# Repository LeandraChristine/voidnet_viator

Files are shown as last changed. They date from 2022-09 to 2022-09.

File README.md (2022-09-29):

# voidnet_viator
Scripts, code and printable 3d-files for the Voidnet Viator Cyberdeck

## Description
A savage, retro-cyberpunk inspired Cyberdeck with a focus on human interface, finished for the Hackaday Cyberdeck challenge 2022.

Built to be a heavy-haptics, typing-friendly and portable device with a comparatively low profile the Viator also features a few add-ons for hardware hacking.
The custom made high ergonomic roll-pin mouse pointer allows typing on the mechanical keyboard and mouse movement in the same hand position.
This interface is supported by a wide-screen touchscreen, a psp-knob used for scrolling, stereo speakers, USB Hub, a tiny status OLED, GPIO switches + LEDs, and a
CharliePlex visualization of the currently used memory.
To enable project building, 5V power is supplied via two banana jacks and a 8 channel signal analyzer mounted under the keyboard.
A grip handle, cable-containing shoulder strap, flashlight and two 18650 Lion cells make the Viator a viable companion for your next run.

## Links
Video: https://clipchamp.com/watch/iuDfoU8I1nf

3d Model overview - Fusion: https://a360.co/3SyB80R

3d Files and Scripts - Github: https://github.com/LeandraChristine/voidnet_viator

Build - Hackerspace WIKI: https://www.hackerspace-ffm.de/wiki/index.php?title=Voidnet_Viator_Cyberdeck

## BOM

Other than the 3d printed parts (all FDM parts printed in black PETG, all Resin printed in Elegoo ABS-like clear-red) the following was used:

### Base
- Raspberry Pi 4 (+SD card)
- Corsair K65 RGB 60% mechanical keyboard (don't get too attached to it)
- Waveshare Raspberry Pi 7.9 inch Capacitive LCD HDMI Display 400 x 1280 (comes with great Raspi HDMI and USB connectors)
- Geekworm Raspberry Pi UPS, X728 V2.1 (or alternative)
- 2x 18650 (unprotected due to the X728 spacing) Lion cells
- 2x Goobay 4-Port USB 2.0 Hub (needs a super slim form factor to fit. I used this: https://www.berrybase.de/4-port-usb-2.0-hub-mit-0-4m-anschlusskabel-farbe-schwarz)
- Stero USB Speaker (2 x 0,5W, I used: https://www.berrybase.de/externer-usb-mini-lautsprecher-schwarz)
- Alumnium Angle 40mm x 20mm, cut to a length of 290mm (the 3d files include 2 drill-guides to help get the holes right)
- 3x 4mm Brass rods ~330mm length (cut a 1m part into 3, to clamp the 3d printed parts cut a thread at the end of each rod)
- M4 Nuts to secure the clamping shell to the brass rods
- M2 cylinder screws of various lengths
- M2.5 screws and standoffs of various lengths (for the raspi, USP and waveshare display)
- M3 cylinder screws of various lengths
- Wiring (e.g. 0.14mm), Connectors and general soldering stuff
- Some USB and MINI-USB connectors to solder (to configure custom wires that are slim enough below the keyboard)
- Threaded inserts / Knurled Nuts (M3) (pretty much used everywhere)
- (optional) microSD / T-Flash to microSD extension (to get to the SD card easier)

### Rolling mouse
- 8mm stainless steel shaft
- 3x IGUS drylin® R Lineargleitbuchse RJUM-01 (or LM8UU, but it will not feel as nice and smooth)
- optics, chip and bits off a cheap, wired, optical mouse (I used ISY ICM-1000, which has a A2803 optical mouse sensor: http://www.nst-ic.com/nstfileupload/productsinfo/20190703095231_293.pdf)

### Additional Features
- Adafruit 15x7 CharliePlex LED Matrix Display FeatherWing - Red
- Adafruit OLED for Raspberry Pi Pico, 128x32, I2C (scratch that, it died randomly and was replaced by a Generic 0.91 Inch, White 128X32 I2C OLED)
- AZDelivery Logic Analyzer 8 CH, 24MHz
- 2x 4mm Banana Jacks (22mm length, one red, one black...I did not like the red I got so a 3d file for resin printing your own is included)
- InLine 33441G USB 3.1 Adaptercable Male C to Female C (for the charging port connected to the UPS)
- 0.28" mini Digital Voltmeter Display
- (optional) 4x WAGO 221-412 2 Fach clamps (to expose the I2C Bus on the backside)
- PSP Slim analog Controller Joystick
- Teensy LC (to generate a HID Keyboard and Mouse, you can try a different controller here....but I had some issues with the Circuitpython ones)
- 7x different color 5mm LEDS (and resistors matched to the GPIO output)
- 7x LED housing for 5mm leds (I used Signal Construct 1089)
- 4x Miniature Toggle Switch (I scavenged for these, you can also use any other switches or buttons that fit in the front panel)
- Hefty, vandalism-safe Button with LED indicator for 10mm hole (power button, there is plenty of space reserved for this in the housing so even longer models should fit)
- 5mm hole momentary switch (for below the screen, wired to the waveshare display's on/off switch so it can be used to conserve power)

### Handle
- Bike Handle Grip (Diameter: ~24 mm. Length: ~ 110 mm, cut to size)
- Aluminum Pipe 24mm OD, 20mm ID
- M5 threaded rod ~140mm length
- 2x M5 Ring nut (screws to the threaded rod)

### Strap
- 2x Tactical Belt (so you get two buckles to remove the strap completely)
- Some more M3 Bolts & Nuts
- USB or other cables you wish to carry
- Cable ties (to attach the belt-buckles to the 4mm rods on the main case)

### Greeblies
- 2x CPU cooler above the speaker covers
- 1x rectangular cooler on the left side

### Experimental
- SMALLRIG Ultra Slim 4K HDMI Kabel  Micro HDMI Male to Full HDMI Female 14cm (to expose the 2nd HDMI output on the back, but so far I did not get that to work nicely)

## Build
For info on the building process check the Hack-FFM Wiki: https://www.hackerspace-ffm.de/wiki/index.php?title=Voidnet_Viator_Cyberdeck

### 3d-Files
If you wish to build a similar device you can probably use a lot of the printed parts, while modifying others to suit your needs.
The parts are available on github: https://github.com/LeandraChristine/voidnet_viator

### Scripts

.ino Files in the teensy folder are for the Teensy LC HID device. Flash them to the teensy with your method of choice (e.g. arduino). Make sure to flash as USB Keyboard + Mouse + Joystick

.py Files can be called via crontab (sudo crontab -e, and then add a line like @reboot python3 /pathtothefile to start the script at boot)
stats.py displays some general status of the system on the tiny OLED
shellcharlie.py visualizes the memory status on the CharliePlex display
the GPIO scripts can be modified to trigger LEDs and take input from switches (the example uses side LEDs to show the battery charge)

## THX
HackFFM - https://hackaday.io/hackerspace/167562-hackerspace-ffm (especially for helping with the photo shoot and replacements for suddenly dying hardware)
For the nice background: https://geekprank.com/hacker/simulator/

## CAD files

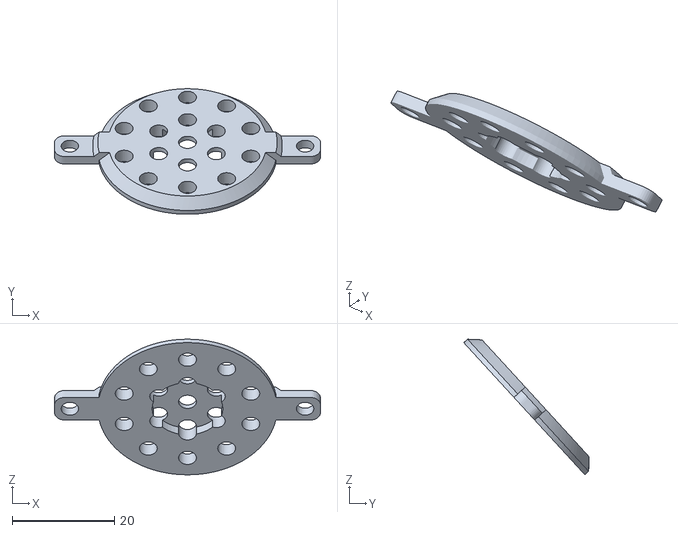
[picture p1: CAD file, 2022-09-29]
3d_files/FDM/Speaker_Cover.stl
51.9 x 24.5 x 26.5

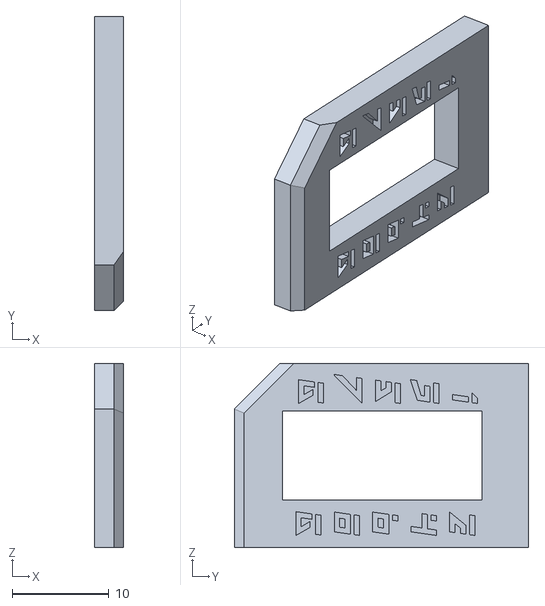
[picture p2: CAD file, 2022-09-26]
3d_files/RESIN/AnalyzerLabel_RESIN.stl
3.00 x 30.4 x 19.0

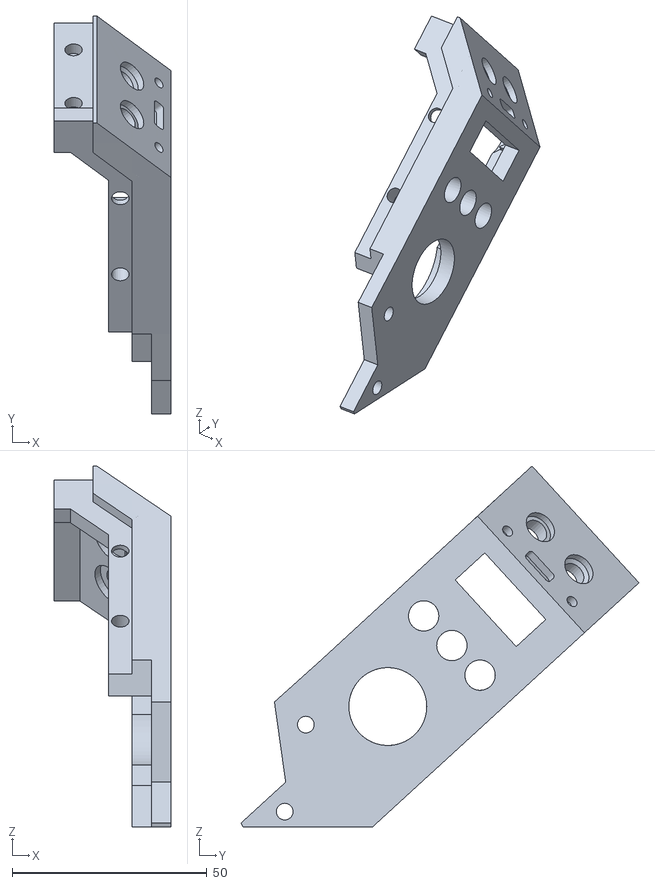
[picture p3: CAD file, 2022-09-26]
3d_files/FDM/Right_Front_Holder.stl
30.0 x 102.2 x 92.6

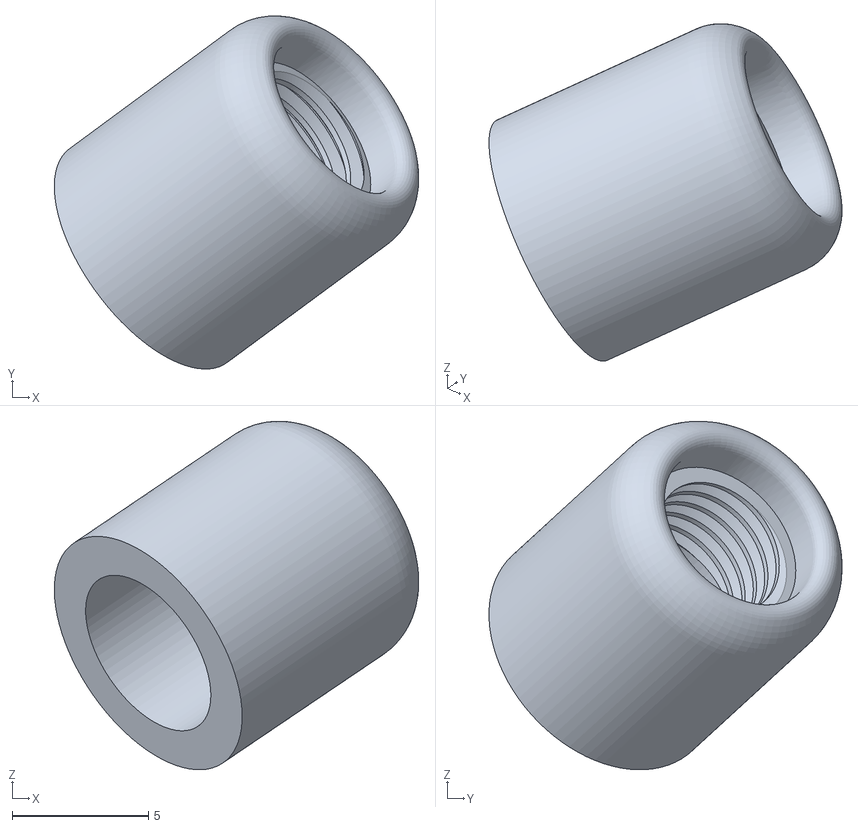
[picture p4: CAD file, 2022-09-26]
3d_files/RESIN/V_Buchse_RESIN.stl
13.4 x 13.0 x 12.8

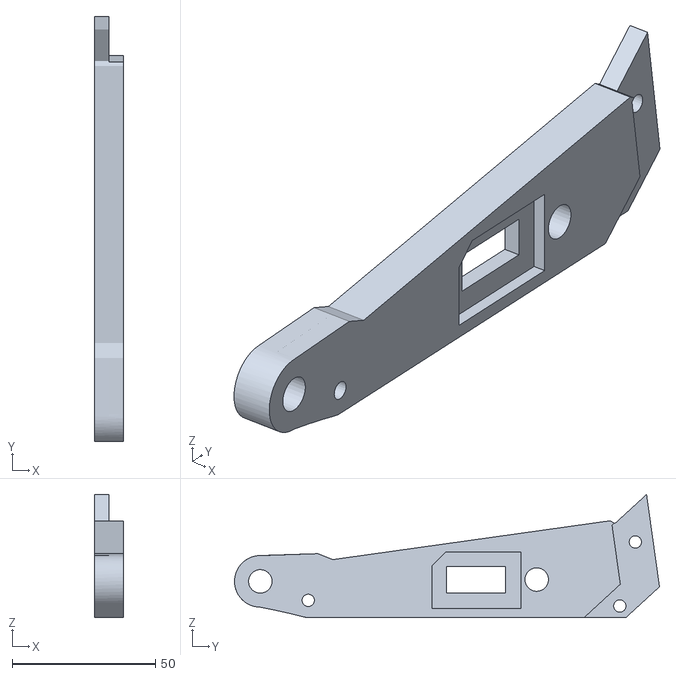
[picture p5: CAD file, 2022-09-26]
3d_files/FDM/Right_Bracket.stl
10.0 x 148.2 x 42.9

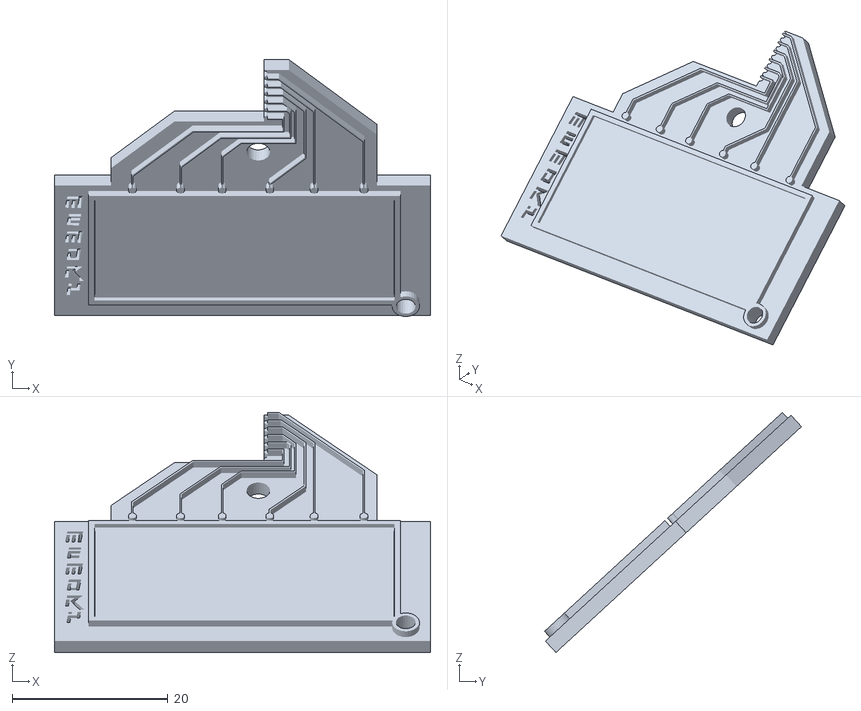
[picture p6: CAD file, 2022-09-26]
3d_files/RESIN/Screen_RESIN.stl
48.4 x 33.1 x 30.9

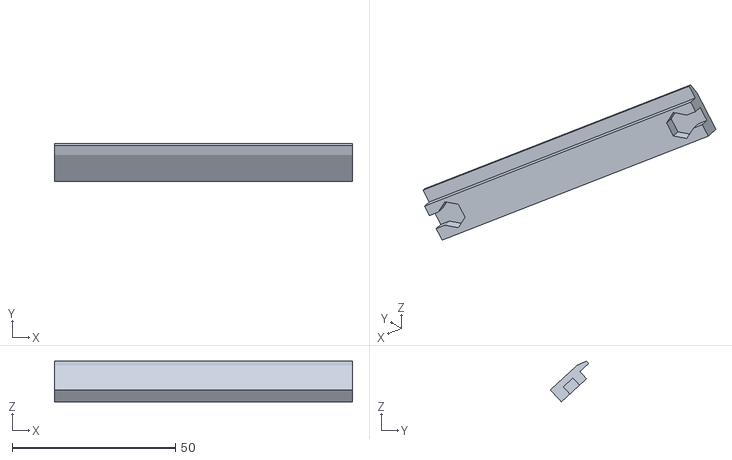
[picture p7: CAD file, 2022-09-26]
3d_files/FDM/Extension_Bot.stl
91.2 x 11.8 x 12.5

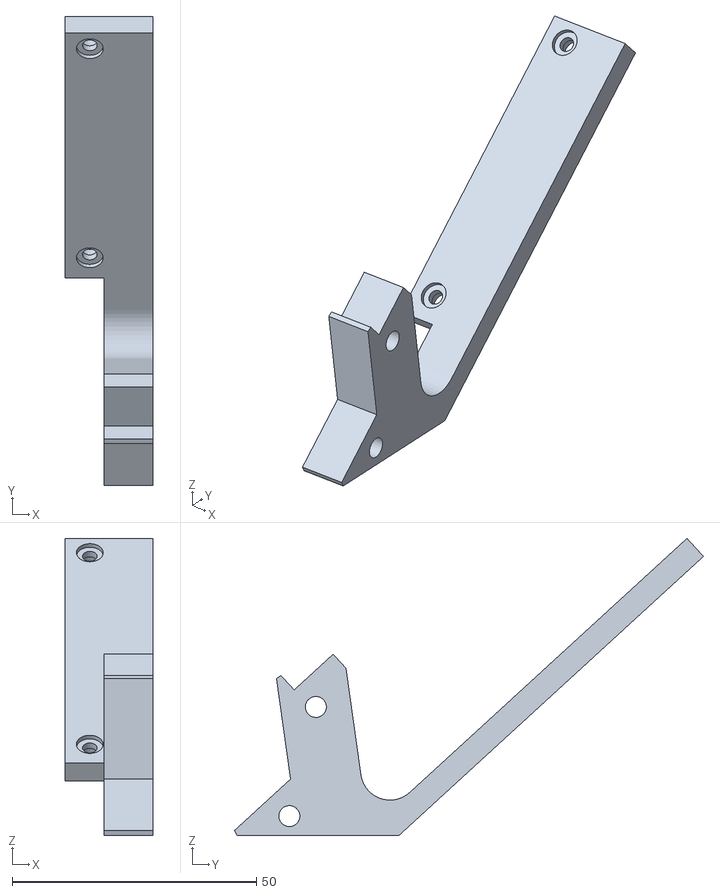
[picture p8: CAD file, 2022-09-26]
3d_files/FDM/Back_Attachment_Broad.stl
18.0 x 96.0 x 60.8

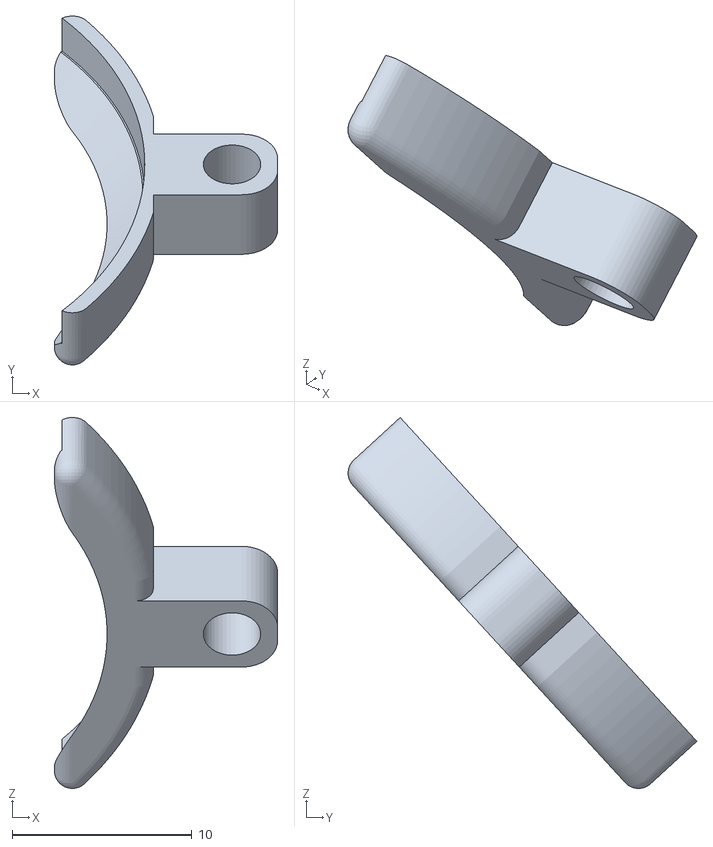
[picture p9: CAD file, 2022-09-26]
3d_files/FDM/Speaker_Holder.stl
12.4 x 19.4 x 20.7

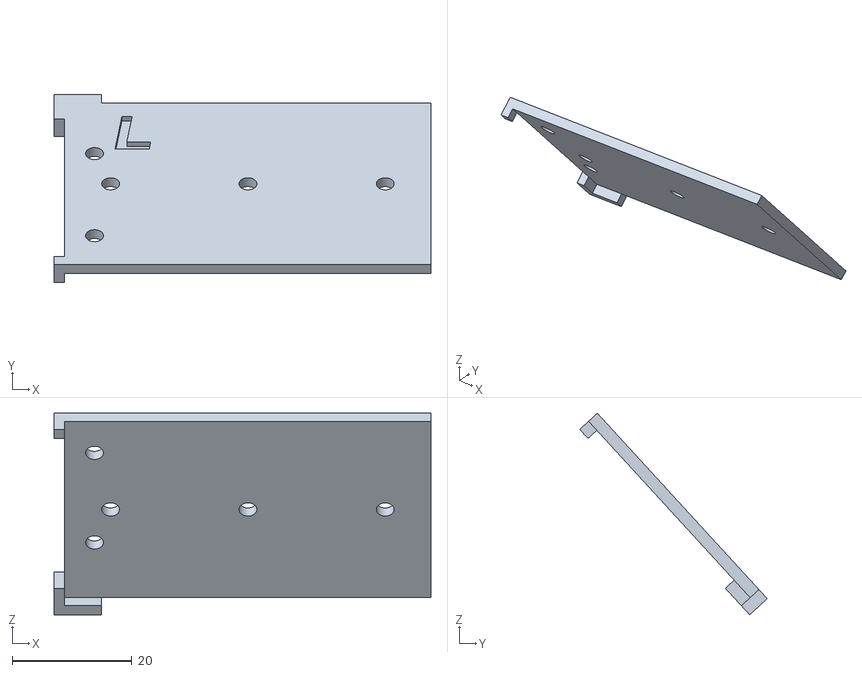
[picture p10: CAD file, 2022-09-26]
3d_files/FDM/Drillguide_Left.stl
63.0 x 31.4 x 33.7

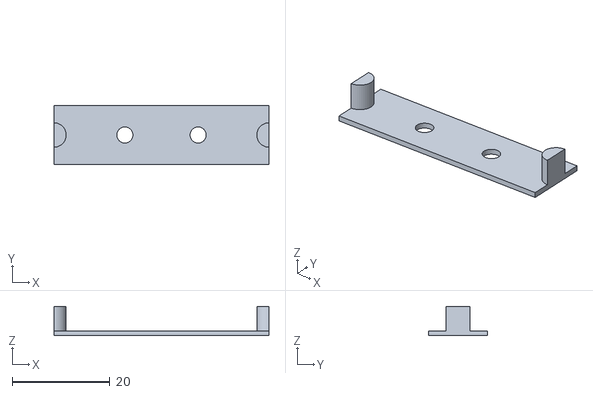
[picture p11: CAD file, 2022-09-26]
3d_files/FDM/Cable_Clamp_Bot.stl
44.0 x 12.0 x 6.00

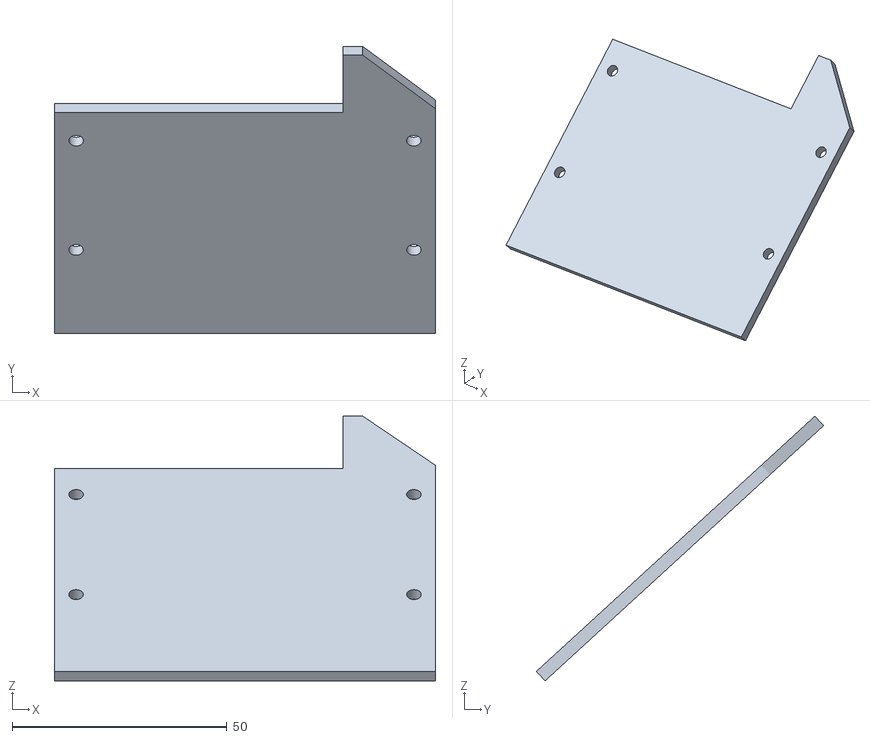
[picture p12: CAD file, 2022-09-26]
3d_files/FDM/Backplate_2.stl
88.7 x 66.9 x 61.6

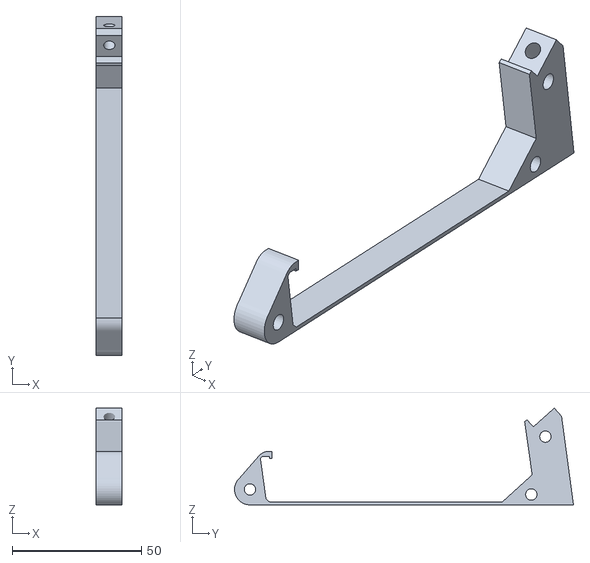
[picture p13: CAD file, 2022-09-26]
3d_files/FDM/Stable_Bracket.stl
10.0 x 130.9 x 37.4

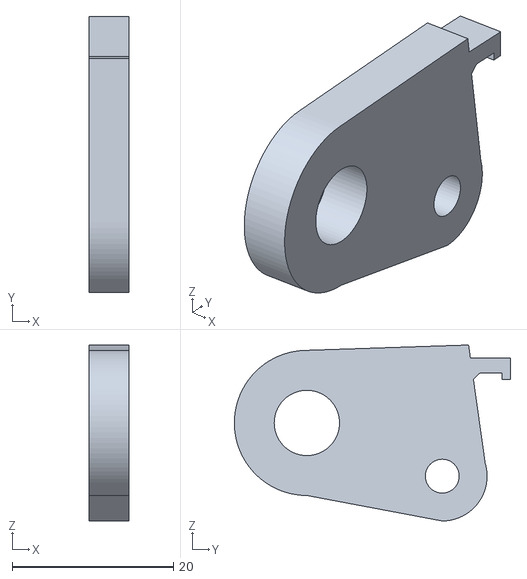
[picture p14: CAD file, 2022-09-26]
3d_files/FDM/Axel_Clamp.stl
5.00 x 34.3 x 21.8

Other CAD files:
3d_files/FDM/Left_Bracket.stl
3d_files/FDM/Optical_Mouse_Cover.stl
3d_files/FDM/Optical_Mouse_Casing.stl
3d_files/FDM/Backplate_1.stl
3d_files/FDM/Back_Attachment_Left.stl
3d_files/FDM/Backplate_3.stl
3d_files/FDM/Cable_Clamp_Top.stl
3d_files/FDM/Display_Panel.stl
3d_files/FDM/Drillguide_Right.stl
3d_files/FDM/Extension_Top.stl
3d_files/FDM/FrontPanel_Clip.stl
3d_files/FDM/Grip_Holder_Back.stl
3d_files/FDM/Grip_Holder_Front.stl
3d_files/FDM/Left_Front_Holder.stl
3d_files/FDM/Left_Panel.stl
3d_files/FDM/Right_Panel.stl

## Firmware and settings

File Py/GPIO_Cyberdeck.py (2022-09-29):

import RPi.GPIO as GPIO
import time
import struct
import smbus
import sys

# Global settings
# GPIO is 26 for x728 v2.0 v2.1 v2.2, GPIO is 13 for X728 v1.2/v1.3
#GPIO_PORT 	= 26 right now used by a LED in the wiring...might have to change that...
I2C_ADDR    = 0x36 #address of the power mgt chip in the X728

LED_FRONT_0 = 6
LED_FRONT_1 = 13
LED_FRONT_2 = 19
LED_FRONT_3 = 26

LED_SIDE_BACK = 23
LED_SIDE_MID = 24
LED_SIDE_FRONT = 25

SW_1 = 21
SW_2 = 20
SW_3 = 16
SW_4 = 12

LEDS_FRONT = [LED_FRONT_0, LED_FRONT_1, LED_FRONT_2, LED_FRONT_3]
LEDS_SIDE = [LED_SIDE_FRONT, LED_SIDE_MID, LED_SIDE_BACK]
LEDS = LEDS_FRONT + LEDS_SIDE
SWITCHES = [SW_1, SW_2, SW_3, SW_4]


#Function from the SW example on the X728 project page
def readVoltage(bus):

     address = I2C_ADDR
     read = bus.read_word_data(address, 2)
     swapped = struct.unpack("<H", struct.pack(">H", read))[0]
     voltage = swapped * 1.25 /1000/16
     return voltage

#Function from the SW example on the X728 project page
def readCapacity(bus):

     address = I2C_ADDR
     read = bus.read_word_data(address, 4)
     swapped = struct.unpack("<H", struct.pack(">H", read))[0]
     capacity = swapped/256
     return capacity

bus = smbus.SMBus(1) # 0 = /dev/i2c-0 (port I2C0), 1 = /dev/i2c-1 (port I2C1)

GPIO.setmode(GPIO.BCM)

for LED in LEDS:
    GPIO.setup(LED, GPIO.OUT)
    #print("LED out set " + str(LED))
    
for SW in SWITCHES:
    GPIO.setup(SW, GPIO.IN, pull_up_down=GPIO.PUD_UP)
    #print("SW in set " + str(SW))

switch_dict = dict(zip(SWITCHES, LEDS_FRONT))

for LED in LEDS:
    time.sleep(0.3)
    GPIO.output(LED ,GPIO.HIGH)
    #print("LED on " + str(LED))

time.sleep(0.7)

for LED in LEDS:
    time.sleep(0.2)
    GPIO.output(LED, GPIO.LOW)
    #print("LED off " + str(LED))
    
while True:
    for SW in SWITCHES:
        GPIO.output(switch_dict[SW],GPIO.input(SW))
        #print ("SW " + str(SW) + " is " + str(GPIO.input(SW)))
        
        #PUT THINGS TO TRIGGER WITH SWITCHES HERE
        
    #Battery charge state display on side LEDs
    capacity = readCapacity(bus)
    #print ("Battery: " + str(capacity))
    if capacity >= 80:
        GPIO.output(LED_SIDE_FRONT,1)
    else:
        GPIO.output(LED_SIDE_FRONT,0)
    if capacity >= 50:
        GPIO.output(LED_SIDE_MID,1)
    else:
        GPIO.output(LED_SIDE_MID,0)
    if capacity>= 20:
        GPIO.output(LED_SIDE_BACK,1)
    else:
        GPIO.output(LED_SIDE_BACK,0)
        

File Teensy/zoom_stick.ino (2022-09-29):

//Turns teensy-lc and psp-stick into a scroll & zoom device. Flash using USB-Type Keyboard + Mouse + Joystick.

#define deadzone 40 //+/- this value will not send a signal
#define offset 480 // compensation for the value on the stick in the neutral position
#define min_analog 120
#define max_analog 840
#define min_speed 0
#define max_speed 2

int analog_hor = A0;
int analog_ver = A1;
int hor = 0;  // variable to store the value read
int ver = 0;  // variable to store the value read

int normalizeInput(int val) {
  val = val - offset;

  if (val < deadzone && val >= -deadzone) {
    val = 0;
  }

  return val;
}

int rescale (int val) {
  int range_analog = max_analog - min_analog;
  int range_speed = max_speed - min_speed;
   
  float percent = (float)val / (float) range_analog * 2.0;
  
  float scaled_speed = percent * range_speed;
  //Serial.println(scaled_speed);
  return (int) scaled_speed;
}

void setup() {
  //Serial.begin(9600);           //  setup serial
  Keyboard.begin();
}

void loop() {
  hor = analogRead(analog_hor);  //signal from left/right tilt of stick
  ver = analogRead(analog_ver);  //signal from up/down tilt of stick

  int scroll_ver = rescale(normalizeInput(ver));
  if (scroll_ver != 0) Mouse.move(0,0,scroll_ver);

  int scroll_hor = rescale(normalizeInput(hor));
  if (scroll_hor != 0) {
    Keyboard.press(KEY_LEFT_CTRL);
    Mouse.move(0,0,scroll_hor);
    Keyboard.release(KEY_LEFT_CTRL);
  }
  delay(200); //larger delay feels like an indent when scrolling
}

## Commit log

2022-09-26 Added printable 3d files
    [AnalyzerLabel_RESIN.stl, Axel_Clamp.stl, Back_Attachment_Broad.stl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]
2022-09-29 Speaker_cover added
    [Speaker_Cover.stl]
2022-09-29 Added Teensy code
